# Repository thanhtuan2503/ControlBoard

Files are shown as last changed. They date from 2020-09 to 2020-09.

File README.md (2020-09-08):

Leo, the Arduino Leonardo clone done in KiCad.

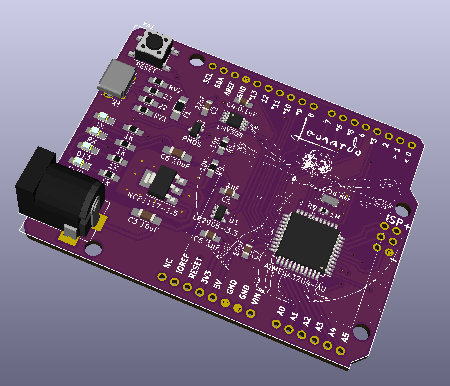
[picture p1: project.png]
 

https://rheingoldheavy.com/arduino-from-scratch-part-5-selecting-comparator-parts/

Bill Of Materials
----------------
  
- 1 ea., Perfect Purple PCB from OSH Park, with not so perfect layout from kicad.pcb file.
- 1 ea., U1 IC REG LINEAR 3.3V 150MA SOT23-5, LP2985-33DBVRG4, https://www.digikey.com/short/j29pqr
- 1 ea., U2 IC OPAMP GP 1MHZ RRO 8VSSOP, LM358DGKR, https://www.digikey.com/short/jnd53r
- 1 ea., U3 IC REG LINEAR 5V 1A SOT223 NCP1117ST50T3G, https://www.digikey.com/short/j29pqc
- 1 ea., U4 ATMEGA32U4-AU, IC MCU 8BIT 32KB FLASH 44TQFP, https://www.digikey.com/short/jb25pc
- 1 ea., Q1 MOSFET P-CH 20V 2A SSOT3, FDN340P, https://www.digikey.com/short/j29ppj

- 1 ea., Y1 CER RES 16.0000MHZ 15PF SMD, CSTCE16M0V53-R0, https://www.digikey.com/short/j2b9cm
- 2 ea., C1, C5 CAP CER 1UF SMD 0805
- 1 ea., C2 CAP CER 22pF SMD 0805
- 2 ea., C3, C6, C7 CAP CER 10UF 25V 1206, https://www.digikey.com/short/j29pwm
- 1 ea., C4 CAP CER 0.1UF SMD 0805

- 4 ea., D1-D4 SMD LED 0805, https://www.digikey.com/short/jwj4rb
- 1 ea., F1 PTC 1206, Bel 0ZCJ0025AF2E, https://www.digikey.com/short/jfcbc8
- 2 ea., RV1, RV2 VARISTOR 	VARISTOR 10.8V 40A 0805, https://www.digikey.com/short/jwj45d
- 4 ea., R1-R4 Resistor 1K OHM SMD 0805, https://www.digikey.com/short/j2d0wt
- 2 ea., R5, R8 Resistor 10K OHM SMD 0805, https://www.digikey.com/short/j2d0w4
- 2 ea., R6, R7 Resistor 22 OHM SMD 0805, https://www.digikey.com/short/jwj45j
- 1 ea., R9 Resistor 1M OHM SMD 0603, 

- 1 ea., SW1 (yellow) SWITCH TACTILE SPST-NO 0.05A 12V, SW416-ND, https://www.digikey.com/short/jwj4m9
- or (purple) KSEM31J LFS https://www.digikey.com/short/jnqh3m
- 1 ea., X3, CONN RCPT MICRO USB R/A SMD, Molex 1050170001, https://www.digikey.com/short/jb2205
- 1 ea., J1 Barrel Jack, https://www.digikey.com/short/j2fz43
- 1 ea., 6-Pin header, https://www.digikey.com/short/jwj4w4
- 2 ea., 8-Pin header, https://www.digikey.com/short/jwj4dp
- 1 ea., 10-Pin header, https://www.digikey.com/short/jwj4n7
- 1 ea., 2x3 Pin header, http://www.digikey.com/short/3m33n0

License
----------------
[Attribution-ShareAlike 3.0 United States (CC BY-SA 3.0 US)](https://creativecommons.org/licenses/by-sa/3.0/us/)

You are free to:

- Share — copy and redistribute the material in any medium or format
- Adapt — remix, transform, and build upon the material

Under the following terms:

- Attribution — You must give appropriate credit, provide a link to the license, and indicate if changes were made. You may do so in any reasonable manner, but not in any way that suggests the licensor endorses you or your use.
- ShareAlike — If you remix, transform, or build upon the material, you must distribute your contributions under the same license as the original.

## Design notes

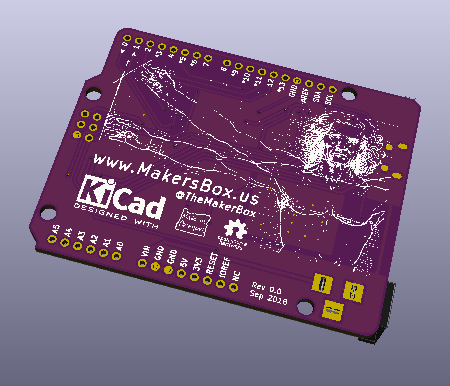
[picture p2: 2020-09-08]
project_back.png

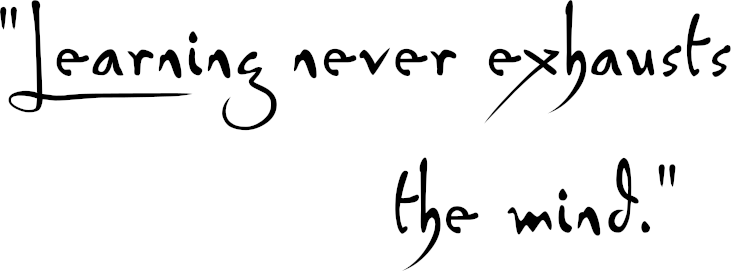
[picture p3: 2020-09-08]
images/quote.png

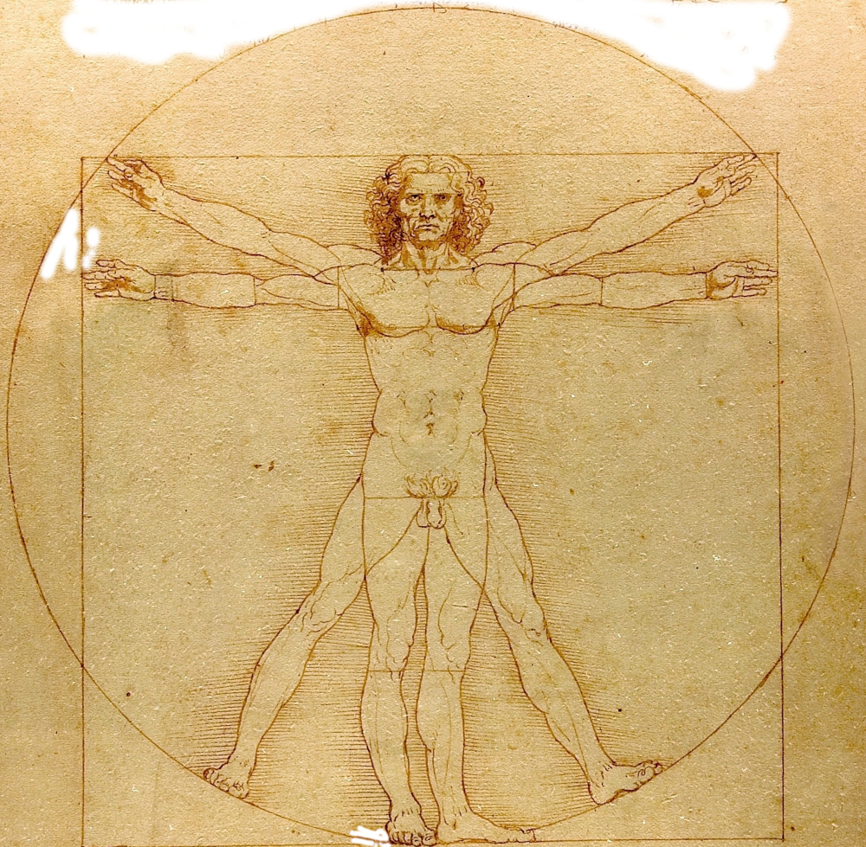
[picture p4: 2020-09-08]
images/Da_Vinci_Vitruve3.jpg

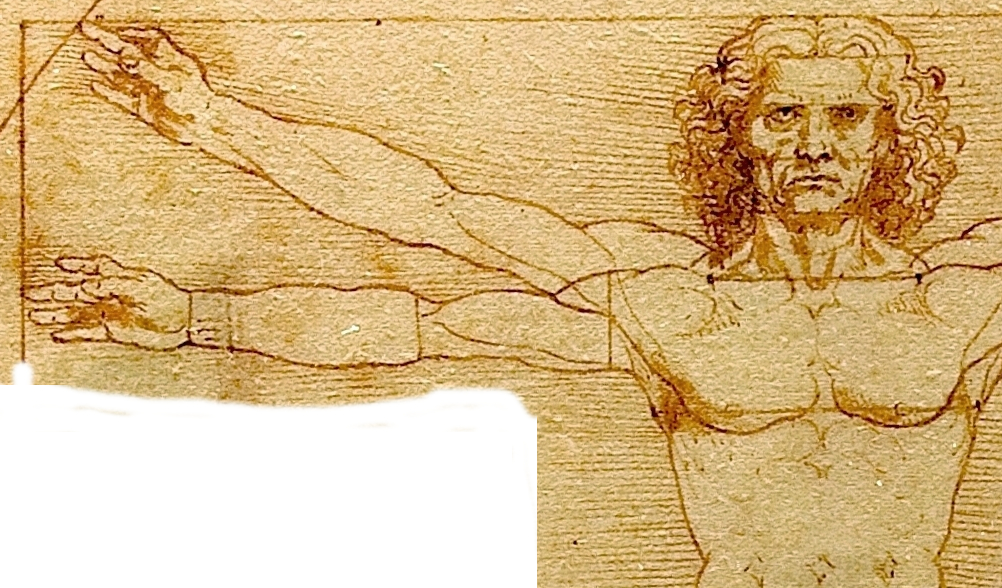
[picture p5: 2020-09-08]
images/Da_Vinci_Vitruve_Luc_Viatour.jpg

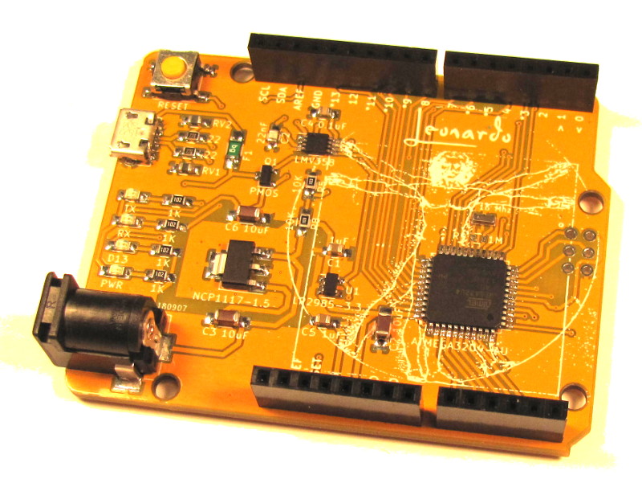
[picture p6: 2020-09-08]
images/front.JPG

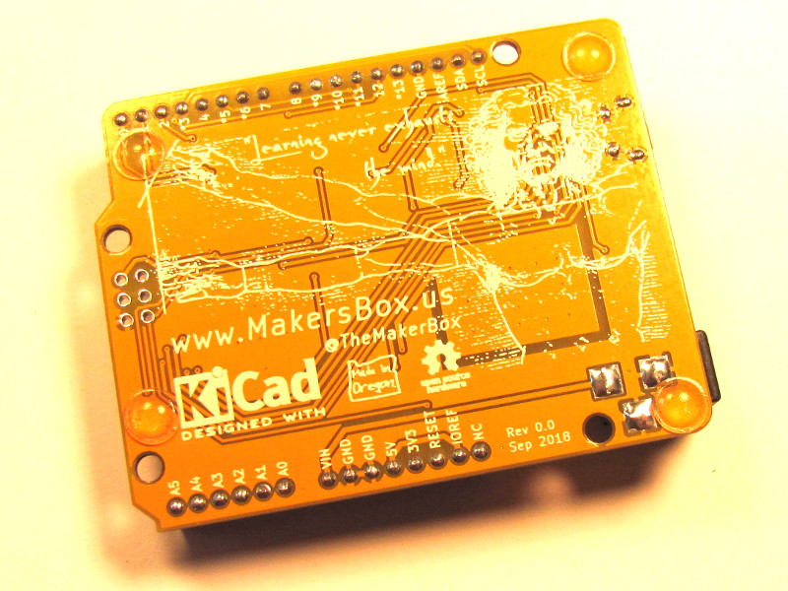
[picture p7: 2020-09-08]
images/back.JPG

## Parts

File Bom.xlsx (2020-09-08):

Description | Manufacturer Part Number | Manufacturer | Digi-Key Part Number | Customer Reference | Quantity | $ at Qty 1 | $ at Qty 25 | Total @ Qty 1 | Tota @ Qty 25
PCB |  | OSH Park | - | - | 1 | $9.48 | $5.72 | $9.48 | $5.72 | ~$2.60 JLCPCB?
IC REG LINEAR 3.3V 150MA SOT23-5 | LP2985-33DBVRG4 | Texas Instruments | 296-49790-1-ND | Leo U1 | 1 | $0.60 | $0.53 | $0.60 | $0.53
IC OPAMP GP 1MHZ RRO 8VSSOP | LMV358IDGKR | Texas Instruments | 296-13455-1-ND | Leo U2 | 1 | $0.80 | $0.71 | $0.80 | $0.71
IC MCU 8BIT 32KB FLASH 44TQFP | ATMEGA32U4-AUR | Microchip Technology | ATMEGA32U4-AURCT-ND | Leo U4 | 1 | $4.20 | $3.85 | $4.20 | $3.85
IC REG LINEAR 5V 1A SOT223 | NCP1117ST50T3G | ON Semiconductor | NCP1117ST50T3GOSCT-ND | Leo U3 | 1 | $0.54 | $0.46 | $0.54 | $0.46
MOSFET P-CH 20V 2A SSOT3 | FDN340P | ON Semiconductor | FDN340PCT-ND | Leo Q1 | 1 | $0.55 | $0.43 | $0.55 | $0.43
CER RES 16.0000MHZ 15PF SMD | CSTCE16M0V53-R0 | Murata Electronics North America | 490-1198-1-ND | Leo Y1 | 1 | $0.50 | $0.42 | $0.50 | $0.42
CAP CER 10UF 35V X5R 1206 | GRM319R6YA106KA12D | Murata Electronics North America | 490-9964-1-ND | Leo C3, C6, C7 | 3 | $0.41 | $0.16 | $1.23 | $0.48
CAP CER 0.1UF 25V X7R 0805 | CC0805KRX7R8BB104 | Yageo | 311-1141-1-ND | Leo C4 | 1 | $0.13 | $0.10 | $0.13 | $0.10
CAP CER 22PF 25V C0G/NP0 0805 | 885012007030 | Wurth Electronics Inc. | 732-7829-1-ND | Leo C2 | 1 | $0.10 | $0.05 | $0.10 | $0.05
CAP CER 1UF 25V X5R 0805 | CL21A105KAFNNNE | Samsung Electro-Mechanics | 1276-2887-1-ND | Leo C1, C5 | 2 | $0.19 | $0.14 | $0.38 | $0.28
PTC RESET FUSE 24V 250MA 1206 | 0ZCJ0025AF2E | Bel Fuse Inc. | 507-1799-1-ND | Leo F1 | 1 | $0.13 | $0.13 | $0.13 | $0.13
VARISTOR 10.8V 40A 0805 | VCUG080050L1DP | AVX Corporation | 478-5584-1-ND | Leo RV1, RV2 | 2 | $0.49 | $0.36 | $0.98 | $0.72
RES SMD 1K OHM 5% 1/8W 0805 | ERJ-6GEYJ102V | Panasonic Electronic Components | P1.0KACT-ND | Leo R1 - R4 | 4 | $0.10 | $0.03 | $0.40 | $0.12
RES SMD 10K OHM 5% 1/8W 0805 | ERJ-6GEYJ103V | Panasonic Electronic Components | P10KACT-ND | Leo R5, R8 | 2 | $0.10 | $0.03 | $0.20 | $0.06
RES SMD 22 OHM 5% 0.4W 0805 | ESR10EZPJ220 | Rohm Semiconductor | RHM22KCT-ND | Leo R6, R7 | 2 | $0.10 | $0.03 | $0.20 | $0.06
CRGCQ 0603 1M0 5% | CRGCQ0603J1M0 | TE Connectivity Passive Product | A130109CT-ND | Leo R9 | 1 | $0.10 | $0.03 | $0.10 | $0.03
LED ORANGE CLEAR SMD | LTST-C170KFKT | Lite-On Inc. | 160-1413-1-ND | Leo D1-D4 | 4 | $0.31 | $0.12 | $1.24 | $0.48
SWITCH TACTILE SPST-NO 0.05A 24V | B3S-1002 | Omron Electronics Inc-EMC Div | SW416-ND | Leo SW1 | 1 | $0.66 | $0.62 | $0.66 | $0.62
CONN RCPT MICRO USB R/A SMD | 1050170001 | Molex, LLC | WM1399CT-ND | Leo X3 | 1 | $0.87 | $0.72 | $0.87 | $0.72
CONN PWR JACK 2X5.5MM SOLDER | PJ-002A | CUI Inc. | CP-002A-ND | Leo J1 | 1 | $0.61 | $0.52 | $0.61 | $0.52
CONN HEADER FEMALE 6POS .1" TIN | PPTC061LFBN-RC | Sullins Connector Solutions | S7004-ND | Leo | 1 | $0.52 | $0.48 | $0.52 | $0.48
CONN HEADER FEMALE 8POS .1" TIN | PPTC081LFBN-RC | Sullins Connector Solutions | S7006-ND | Leo | 2 | $0.65 | $0.61 | $1.30 | $1.22
CONN HEADER FEMALE 10POS.1" TIN | PPTC101LFBN-RC | Sullins Connector Solutions | S7008-ND | Leo | 1 | $0.65 | $0.57 | $0.65 | $0.57
 |  |  |  |  |  |  |  | $26.37 | $18.76

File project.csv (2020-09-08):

Id | Designator | Package | Quantity | Designation | Supplier and ref
1 | G*** | Leo_Front | 1 | LOGO
2 | G*** | Leo_back | 1 | LOGO
3 | G***,G*** | graphic_SDA | 2 | LOGO
4 | SW1 | SW_SPST_PTS645 | 1 | RESET
5 | Y1 | Resonator_SMD_CTSC_1.3mmx3.2mm | 1 | 16 Mhz
6 | C1,C5 | C_0805_HandSoldering | 2 | 1uF
7 | C2 | C_0805_HandSoldering | 1 | 22nF
8 | C3,C6 | C_1206_HandSoldering | 2 | 10uF
9 | C4 | C_0805_HandSoldering | 1 | 0.1uF
10 | J3 | BARREL_JACK | 1 | Barrel_Jack
11 | Q1 | SOT-23 | 1 | PMOS
12 | RV1,RV2 | R_0805_HandSoldering | 2 | Varistor
13 | U1 | SOT-23-5 | 1 | LP2985-3.3
14 | U2 | VSSOP-8_3.0x3.0mm_Pitch0.65mm | 1 | LMV358
15 | U4 | TQFP-44_10x10mm_Pitch0.8mm | 1 | ATMEGA32U4-AU
16 | X1 | USB_Micro-B_Molex-105017-0001 | 1 | USB_OTG
17 | XA1 | Arduino_Leonardo_Shield | 1 | Arduino_Leonardo_Shield
18 | U3 | SOT-223-3_TabPin2 | 1 | NCP1117-1.5
19 | D1 | LED_0805_HandSoldering | 1 | PWR
20 | D2 | LED_0805_HandSoldering | 1 | TX
21 | D3 | LED_0805_HandSoldering | 1 | RX
22 | D4 | LED_0805_HandSoldering | 1 | D13
23 | F1 | R_1206_HandSoldering | 1 | Polyfuse
24 | R8,R5 | R_0805_HandSoldering | 2 | 10K
25 | R1,R2,R3,R4 | R_0805_HandSoldering | 4 | 1K
26 | R6,R7 | R_0805_HandSoldering | 2 | 22
27 | R9 | R_0603 | 1 | 1M
28 | REF*** | KiCad-Logo2_8mm_SilkScreen | 1 | KiCad-Logo2_8mm_SilkScreen
29 | VAL | MadeInOregonRev25 | 1 | MadeInOregonRev25
30 | REF*** | OSHW-Logo_5.7x6mm_SilkScreen | 1 | OSHW-Logo_5.7x6mm_SilkScreen
31 | C7 | C_1206_HandSoldering | 1 | 10uF

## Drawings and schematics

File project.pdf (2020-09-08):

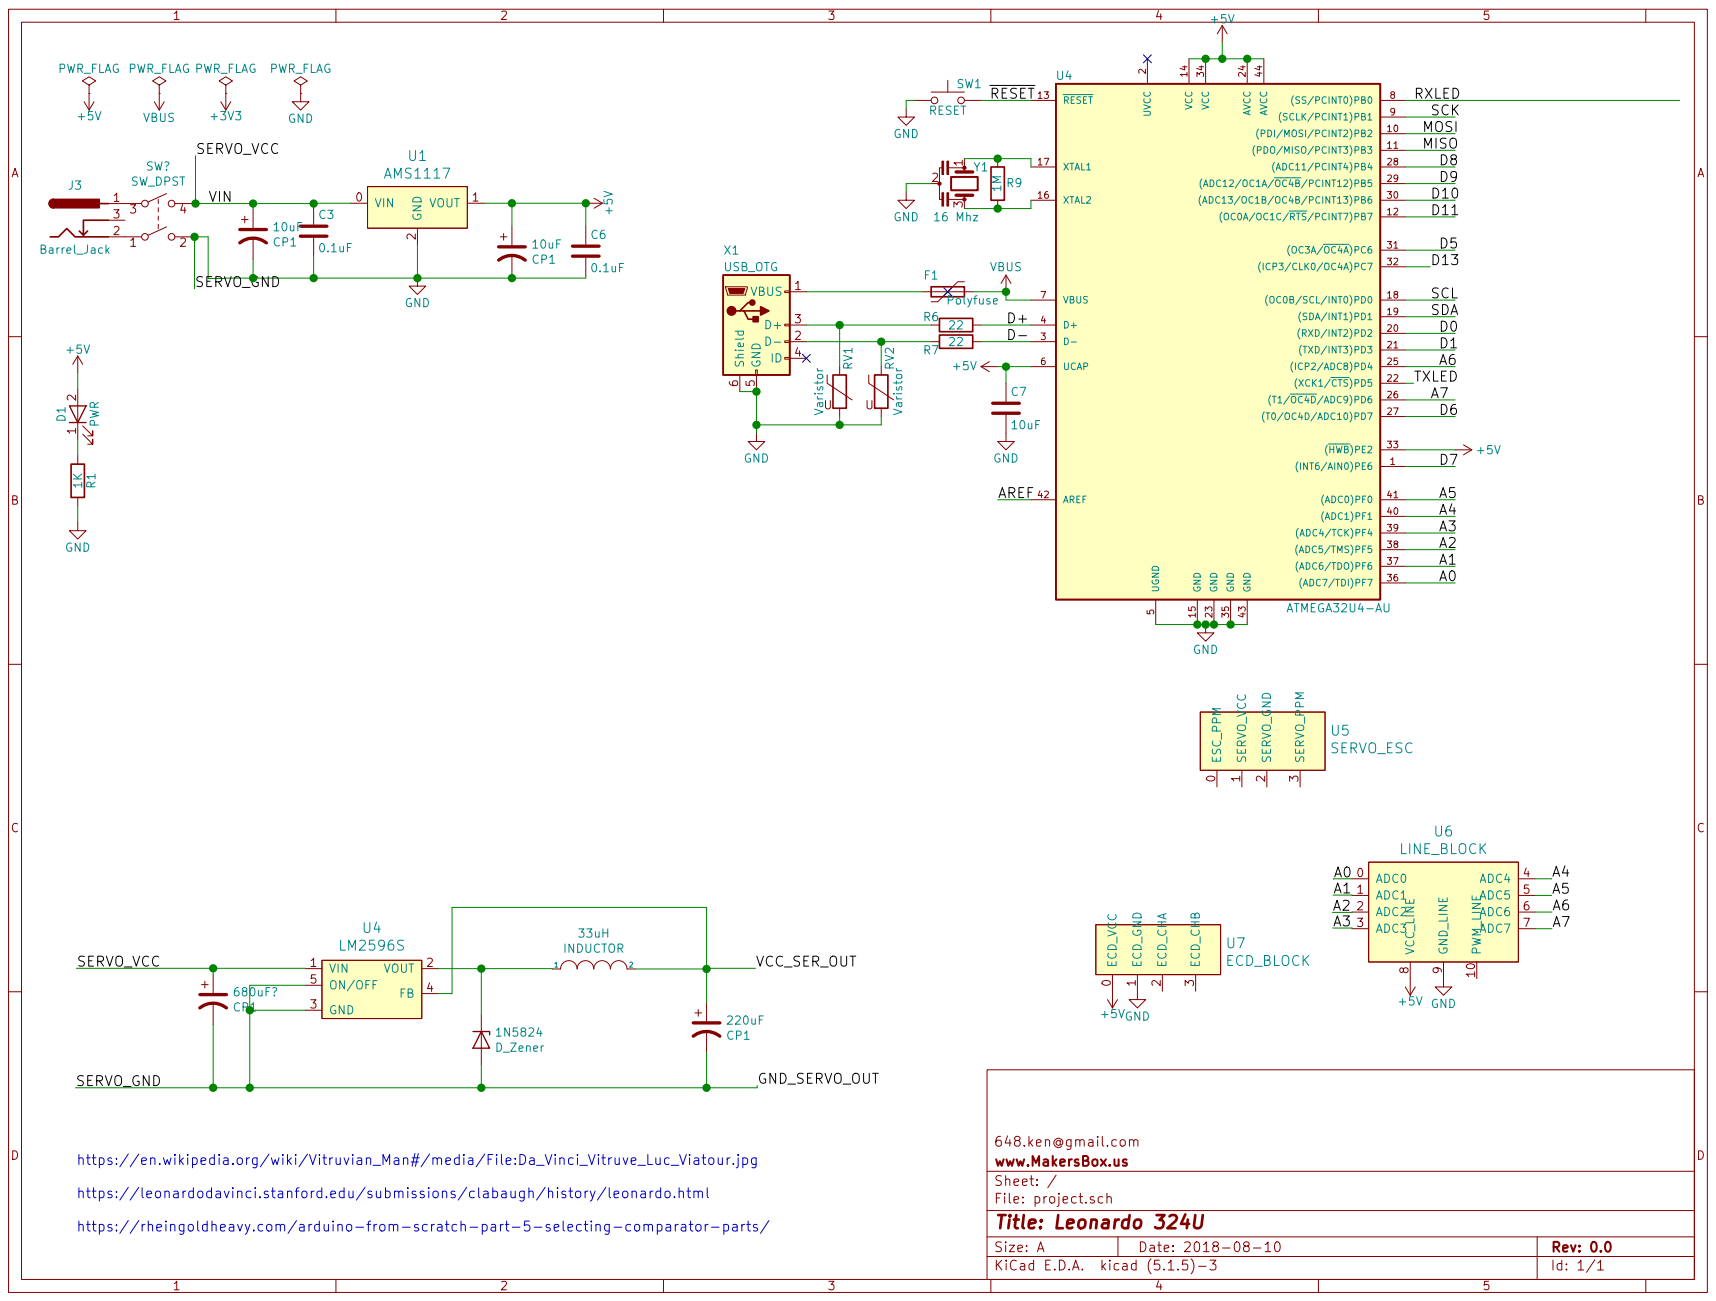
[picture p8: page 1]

648.ken@gmail.com
File: project.sch Sheet: / www.MakersBox.us

https://en.wikipedia.org/wiki/Vitruvian_Man#/media/File:Da_Vinci_Vitruve_Luc_Viatour.jpg

https://leonardodavinci.stanford.edu/submissions/clabaugh/history/leonardo.html

https://rheingoldheavy.com/arduino-from-scratch-part-5-selecting-comparator-parts/

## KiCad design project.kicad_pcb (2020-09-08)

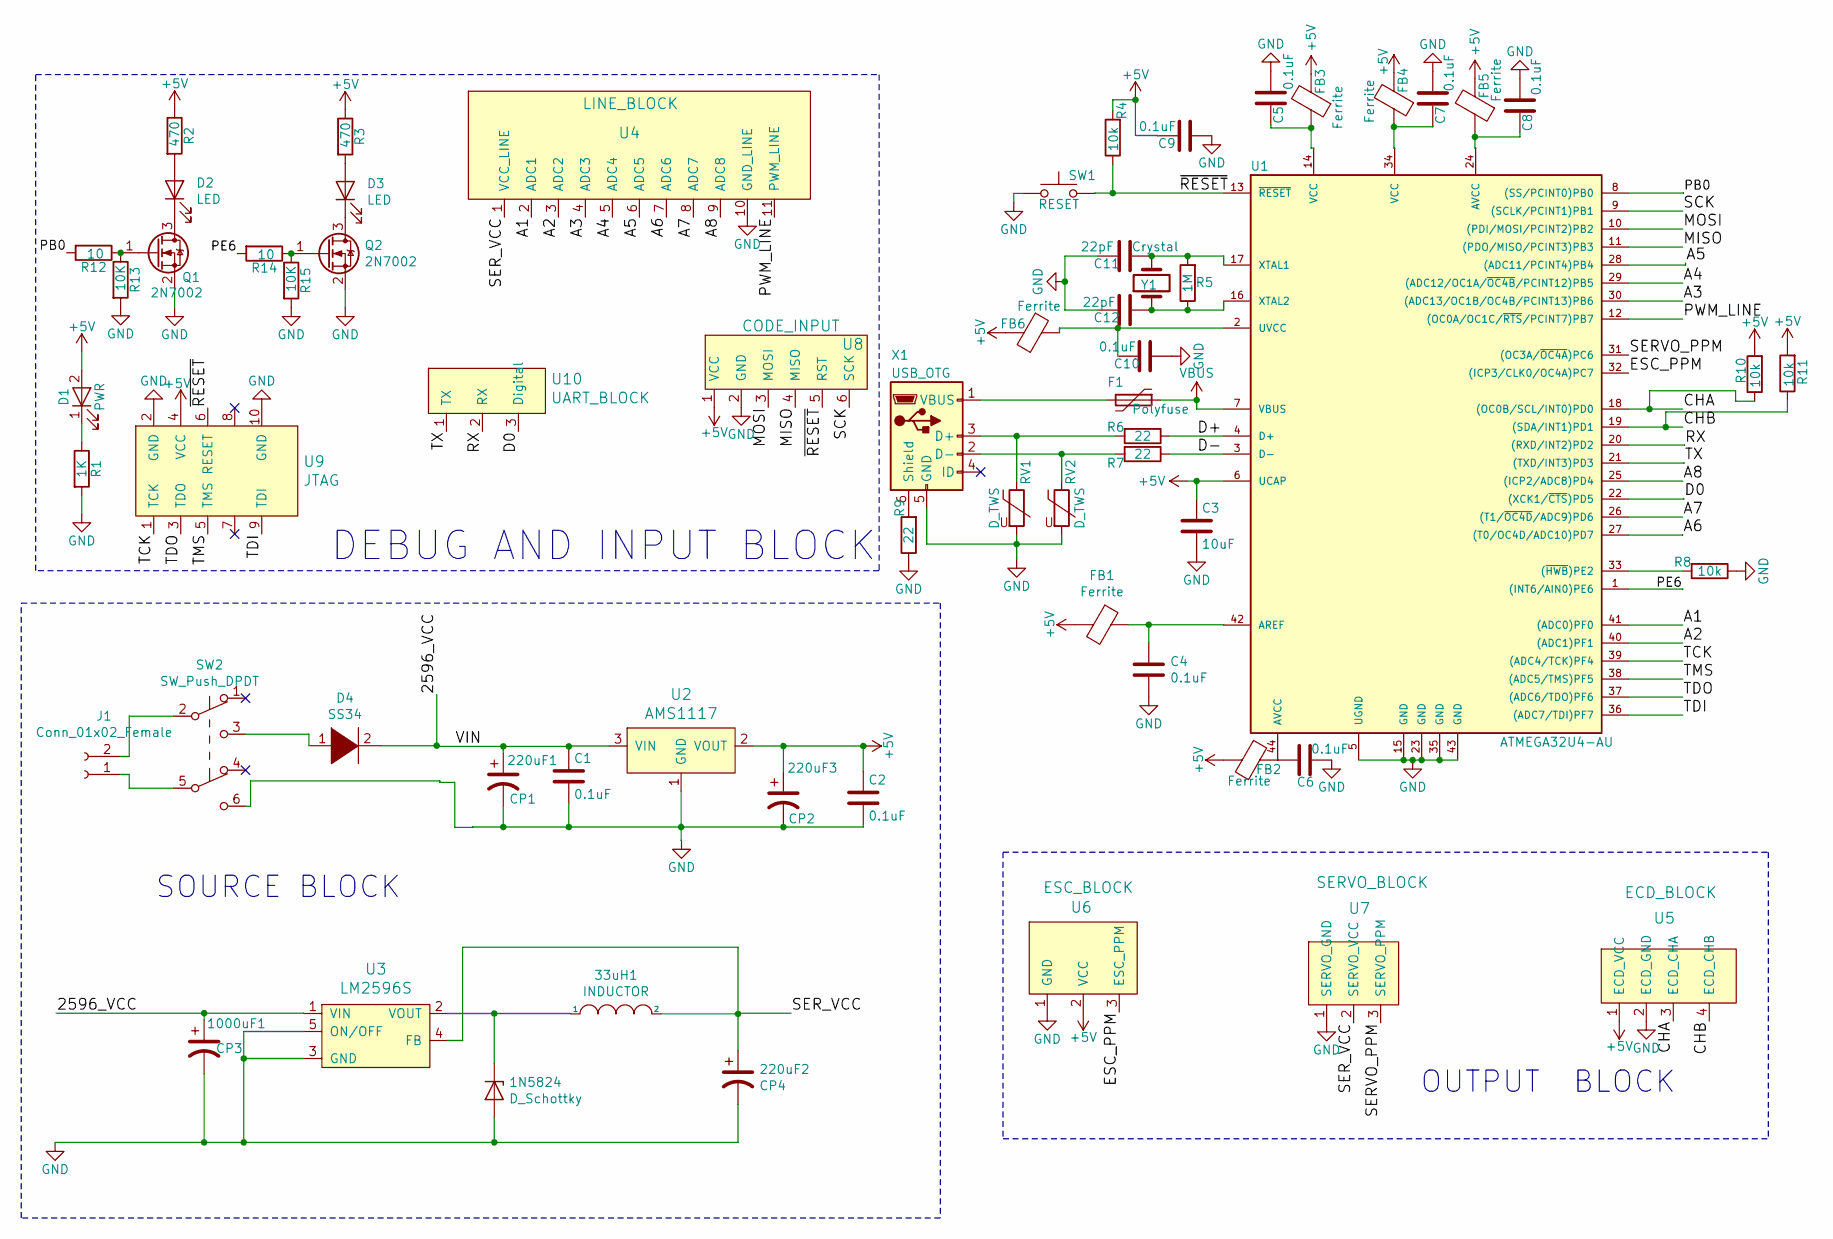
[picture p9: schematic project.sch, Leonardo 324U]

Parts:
1N5824: D_Schottky; SS34_SMC
33uH1: INDUCTOR; L_12x12mm_H8mm
220uF1: CP1; C_Elec_6.3x7.7
220uF2: CP4; C_Elec_6.3x7.7
220uF3: CP2; C_Elec_6.3x7.7
1000uF1: CP3; C_Elec_10x10.2
C1, C2, C4, C5, C6, C7, C8, C9, C10: 0.1uF; C_1206_3216Metric
C3: 10uF; C_1206_3216Metric
C11, C12: 22pF; C_1206_3216Metric
D1: PWR; LED_1206_3216Metric
D2, D3: LED; LED_1206_3216Metric
D4: SS34; SS34_SMC
F1: Polyfuse; R_1206_HandSoldering
FB1, FB2, FB3, FB4, FB5, FB6: Ferrite; FerriteBead
J1: Conn_01x02_Female; TerminalBlock_bornier-2_P5.08mm
Q1, Q2: 2N7002; SOT-23
R1: 1K; R_1206_3216Metric
R2, R3: 470; R_1206_3216Metric
R4, R8, R10, R11: 10k; R_1206_3216Metric
R5: 1M; R_1206_3216Metric
R6, R7, R9: 22; R_1206_3216Metric
R12, R14: 10; R_1206_3216Metric
R13, R15: 10K; R_1206_3216Metric
RV1, RV2: D_TWS; R_0805_HandSoldering
SW1: RESET; SW_SPST_PTS645
SW2: SW_Push_DPDT; Switch
U1: ATMEGA32U4-AU; TQFP-44_10x10mm_Pitch0.8mm
U2: AMS1117
U3: LM2596S; LM2596S-5V
U4: LINE_BLOCK; PinHeader_1x11_P2.54mm_Vertical_SMD_Pin1Right
U5: ECD_BLOCK; TerminalBlock_bornier-4_P5.08mm
U6: ESC_BLOCK; TerminalBlock_bornier-3_P5.08mm
U7: SERVO_BLOCK; TerminalBlock_bornier-3_P5.08mm
U8: CODE_INPUT; PinHeader_2x03_P2.54mm_Vertical_SMD
U9: JTAG; PinHeader_2x05_P2.54mm_Vertical_SMD
U10: UART_BLOCK
X1: USB_OTG; USB_Micro-B_Molex-105017-0001
Y1: Crystal

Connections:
+5V: 220uF3.1, C2.1, C3.1, C9.2, D1.2 (A), FB1.2, FB2.2, FB3.2, FB4.2, FB5.2, FB6.2, R2.1, R3.1, R4.2, R10.2, R11.2, U1.6 (UCAP), U2.2 (VOUT), U5.1 (ECD_VCC), U6.2 (VCC), U8.1 (VCC), U9.4 (VCC)
/2596_VCC: 220uF1.1, 1000uF1.1, C1.1, D4.2 (A), U2.3 (VIN), U3.1 (VIN)
/A1: U1.41 ((ADC0)PF0), U4.2 (ADC1)
/A2: U1.40 ((ADC1)PF1), U4.3 (ADC2)
/A3: U1.30 ((ADC13/OC1B/OC4B/PCINT13)PB6), U4.4 (ADC3)
/A4: U1.29 ((ADC12/OC1A/~OC4B~/PCINT12)PB5), U4.5 (ADC4)
/A5: U1.28 ((ADC11/PCINT4)PB4), U4.6 (ADC5)
/A6: U1.27 ((T0/OC4D/ADC10)PD7), U4.7 (ADC6)
/A7: U1.26 ((T1/~OC4D~/ADC9)PD6), U4.8 (ADC7)
/A8: U1.25 ((ICP2/ADC8)PD4), U4.9 (ADC8)
/CHA: R10.1, U1.18 ((OC0B/SCL/INT0)PD0), U5.3 (ECD_CHA)
/CHB: R11.1, U1.19 ((SDA/INT1)PD1), U5.4 (ECD_CHB)
/D+: R6.1, U1.4 (D+)
/D-: R7.1, U1.3 (D-)
/ESC_PPM: U1.32 ((ICP3/CLK0/OC4A)PC7), U6.3 (ESC_PPM)
/MISO: U1.11 ((PDO/MISO/PCINT3)PB3), U8.4 (MISO)
/MOSI: U1.10 ((PDI/MOSI/PCINT2)PB2), U8.3 (MOSI)
/PB0: R12.2, U1.8 ((SS/PCINT0)PB0)
/PE6: R14.2, U1.1 ((INT6/AIN0)PE6)
/PWM_LINE: U1.12 ((OC0A/OC1C/~RTS~/PCINT7)PB7), U4.11 (PWM_LINE)
/SCK: U1.9 ((SCLK/PCINT1)PB1), U8.6 (SCK)
/SERVO_PPM: U1.31 ((OC3A/~OC4A~)PC6), U7.3 (SERVO_PPM)
/SER_VCC: 33uH1.2, 220uF2.1, U3.4 (FB), U4.1 (VCC_LINE), U7.2 (SERVO_VCC)
/TCK: U1.39 ((ADC4/TCK)PF4), U9.1 (TCK)
/TDI: U1.36 ((ADC7/TDI)PF7), U9.9 (TDI)
/TDO: U1.37 ((ADC6/TDO)PF6), U9.3 (TDO)
/TMS: U1.38 ((ADC5/TMS)PF5), U9.5 (TMS)
/~RESET: R4.1, SW1.2, U1.13 (~RESET~), U8.5 (RST), U9.6 (RESET)
GND: 1N5824.2 (A), 220uF1.2, 220uF2.2, 220uF3.2, 1000uF1.2, C1.2, C2.2, C3.2, C4.2, C5.1, C6.1, C7.1, C8.1, C9.1, C10.1, C11.2, C12.2, Q1.2 (S), Q2.2 (S), R1.2, R8.1, R9.1, R13.2, R15.2, RV1.2, RV2.2, SW1.1, SW2.6 (C), U1.5 (UGND), U1.15 (GND), U1.23 (GND), U1.35 (GND), U1.43 (GND), U2.1 (GND), U3.3 (GND), U3.5 (ON/OFF), U4.10 (GND_LINE), U5.2 (ECD_GND), U6.1 (GND), U7.1 (SERVO_GND), U8.2 (GND), U9.2 (GND), U9.10 (GND), X1.5 (GND); also elsewhere on the board
unnamed: 1N5824.1 (K), 33uH1.1, U3.2 (VOUT)
unnamed: C4.1, FB1.1, U1.42 (AREF)
unnamed: C5.2, FB3.1, U1.14 (VCC)
unnamed: C6.2, FB2.1, U1.44 (AVCC)
unnamed: C7.2, FB4.1, U1.34 (VCC)
unnamed: C8.2, FB5.1, U1.24 (AVCC)
unnamed: C10.2, FB6.1, U1.2 (UVCC)
unnamed: D1.1 (K), R1.1
unnamed: D2.1 (K), Q1.3 (D)
unnamed: D2.2 (A), R2.2
unnamed: D3.1 (K), Q2.3 (D)
unnamed: D3.2 (A), R3.2
unnamed: D4.1 (K), SW2.3 (C)
unnamed: F1.2, X1.1 (VBUS)
unnamed: J1.1, SW2.5 (B)
unnamed: J1.2, SW2.2 (B)
unnamed: Q1.1 (G), R12.1, R13.1
unnamed: Q2.1 (G), R14.1, R15.1
unnamed 47: C12.1, R5.1, U1.16 (XTAL2), Y1.1; also elsewhere on the board
unnamed 48: C11.1, R5.2, U1.17 (XTAL1), Y1.2; also elsewhere on the board
unnamed: R6.2, RV1.1, X1.3 (D+)
unnamed: R7.2, RV2.1, X1.2 (D-)
unnamed: R8.2, U1.33 ((~HWB~)PE2)
unnamed: R9.2, X1.6 (Shield)
unnamed: U1.20 ((RXD/INT2)PD2), U10.2 (RX)
unnamed: U1.21 ((TXD/INT3)PD3), U10.1 (TX)
unnamed: U1.22 ((XCK1/~CTS~)PD5), U10.3 (Digital)
VBUS: F1.1, U1.7 (VBUS)

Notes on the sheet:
SOURCE BLOCK
OUTPUT BLOCK
DEBUG AND INPUT BLOCK

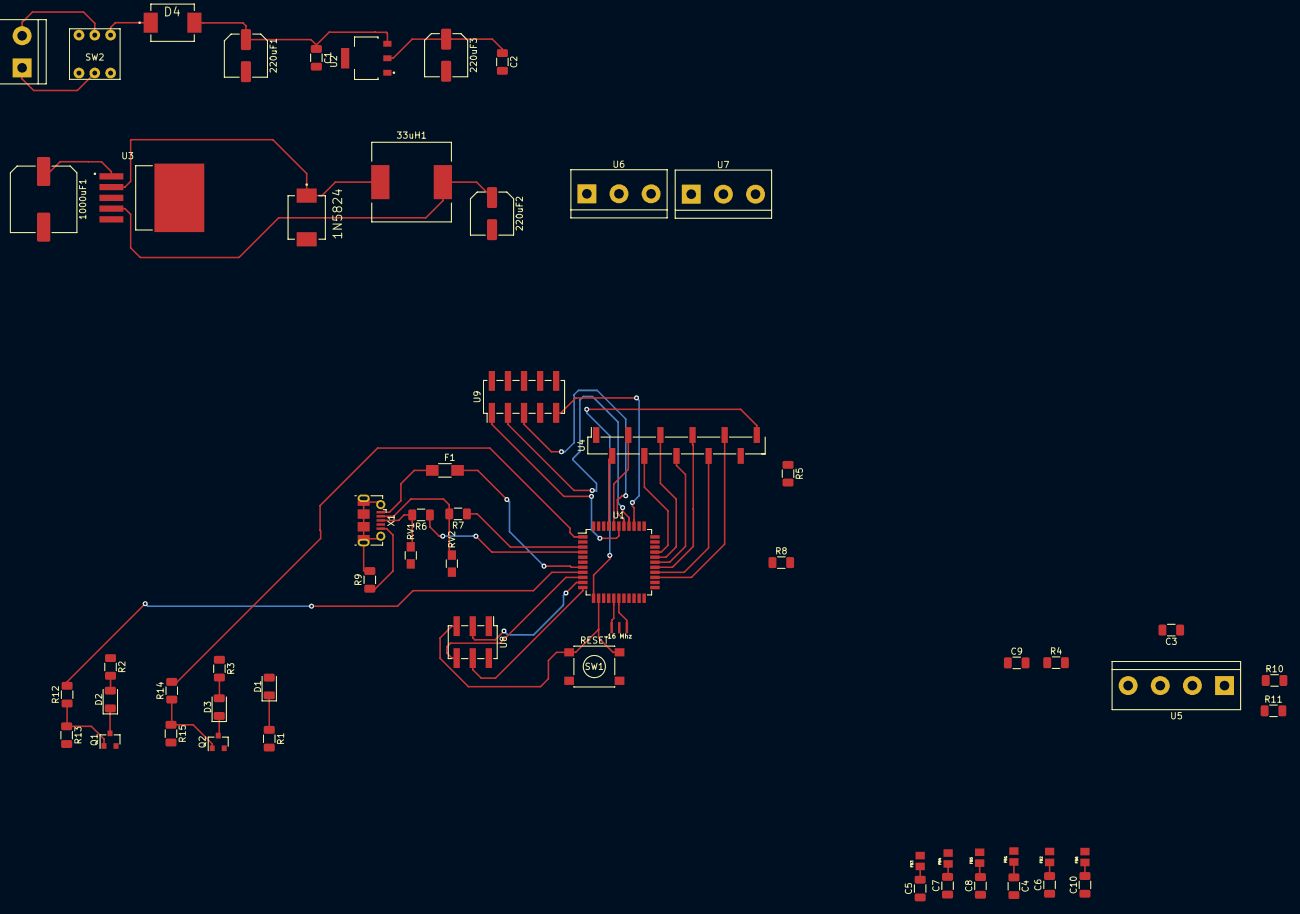
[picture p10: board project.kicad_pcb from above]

Board: 2 copper layers, 60 parts (0 on the bottom side), 54 nets.

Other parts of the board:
Y1_5535: 16 Mhz; Resonator_SMD_CTSC_1.3mmx3.2mm

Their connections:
GND: Y1_5535.2; also elsewhere on the board
unnamed 47: Y1_5535.3; also elsewhere on the board
unnamed 48: Y1_5535.1; also elsewhere on the board

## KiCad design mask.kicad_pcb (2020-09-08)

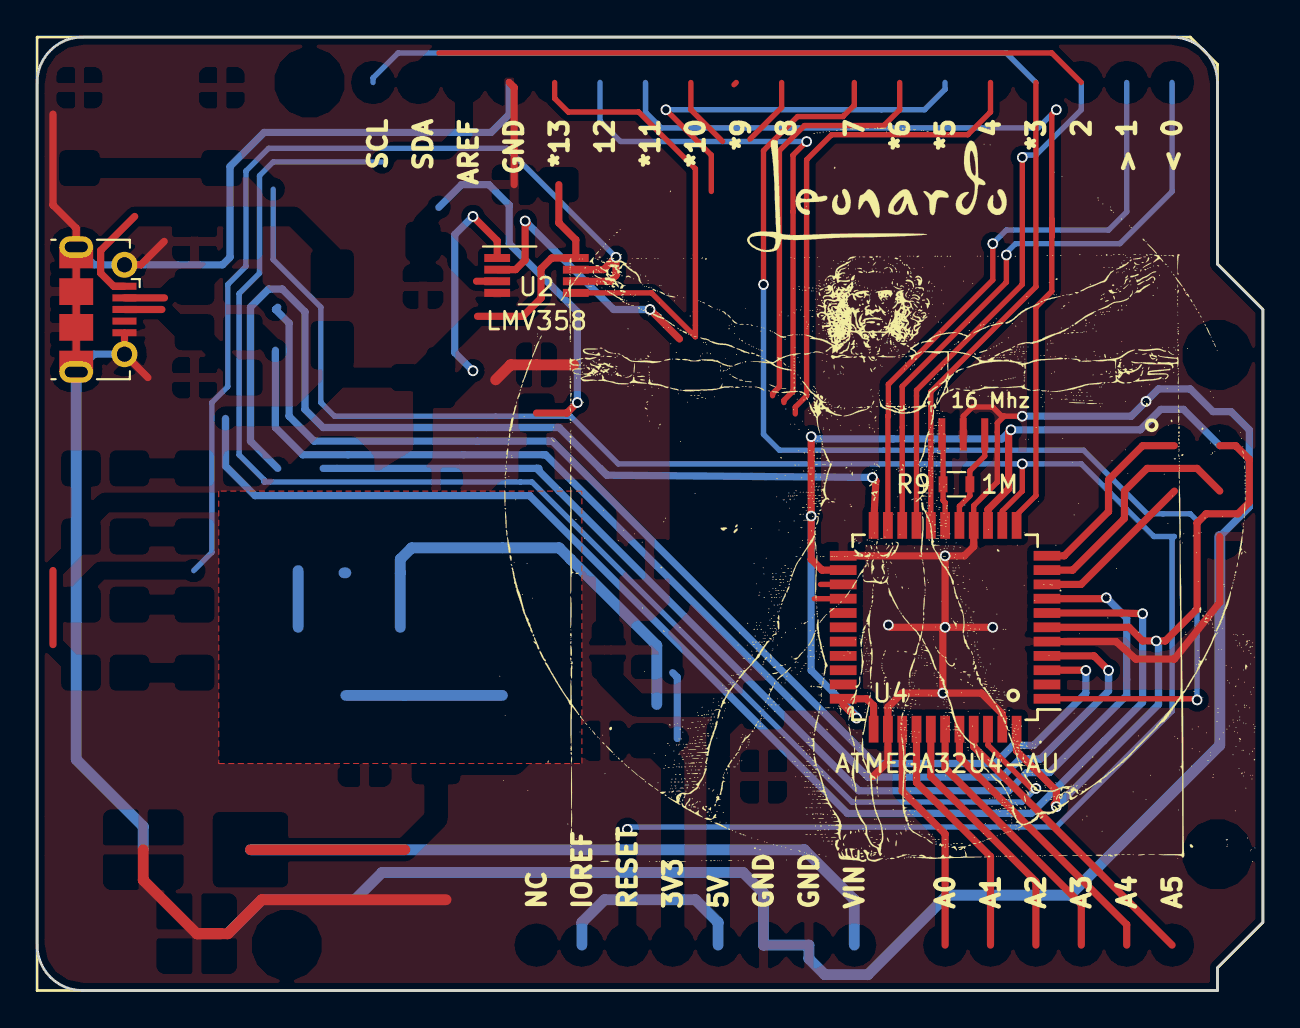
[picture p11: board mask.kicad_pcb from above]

Board: 2 copper layers, 68.6 x 53.3 mm, 6 parts (0 on the bottom side), 6 nets.

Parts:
R9: 1M; R_0603
U2: LMV358; VSSOP-8_3.0x3.0mm_Pitch0.65mm
U4: ATMEGA32U4-AU; TQFP-44_10x10mm_Pitch0.8mm
X1: USB_OTG; USB_Micro-B_Molex-105017-0001
XA1: Arduino_Leonardo_Shield
Y1: 16 Mhz; Resonator_SMD_CTSC_1.3mmx3.2mm

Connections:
+5V: U2.8, U4.6, U4.14, U4.24, U4.33, U4.34, U4.44
/D13: U2.5, U4.32
GND: U2.4, U4.5, U4.15, U4.23, U4.35, U4.43, X1.5, X1.6, Y1.2
unnamed: U2.6, U2.7
unnamed: R9.1, U4.16, Y1.3
unnamed: R9.2, U4.17, Y1.1
